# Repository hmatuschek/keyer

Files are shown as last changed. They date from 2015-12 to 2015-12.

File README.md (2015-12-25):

# Electronic touch CW keyer
This tiny circuit and its firmware implements a simple electronic CW keyer using capacitive touch-paddles. Hence it has absolutely no moving parts which eases the build of the mechanical part of the keyer a lot. 

The central logic of the keyer is implemented in software using a ATTiny 45 MCU. It implements a simple (mode A) electronic CW key. The capacitive touch interface is easy too. It basically measures the capacity of the metal paddles which changes as they get touched with the hand. In fact, the hardware measures the time needed to charge the paddles though a large resistor. This time increases significantly if the paddle is touched. 

The circuit provides a open-collector output to switch even simple transmitters which expect a straight key. Additionally an LED and a side-tone generator are present for practicing. The speed of the keyer can be set using a potentiometer in a range from 10WPM to 42WPM. Please note that the speed gets updated only while the key is idle.

## License
Both, the hard and software are licensed under the terms of the GNU Public License (GPL).

Copyright (C) 2015  Hannes Matuschek <hmatuschek at gmail dot com>

This program is free software; you can redistribute it and/or modify it under the terms of the GNU General Public License as published by the Free Software Foundation; either version 2 of the License, or (at your option) any later version.

This program is distributed in the hope that it will be useful, but WITHOUT ANY WARRANTY; without even the implied warranty of MERCHANTABILITY or FITNESS FOR A PARTICULAR PURPOSE.  See the GNU General Public License for more details.

You should have received a copy of the GNU General Public License along with this program; if not, write to the Free Software Foundation, Inc., 51 Franklin Street, Fifth Floor, Boston, MA 02110-1301 USA.

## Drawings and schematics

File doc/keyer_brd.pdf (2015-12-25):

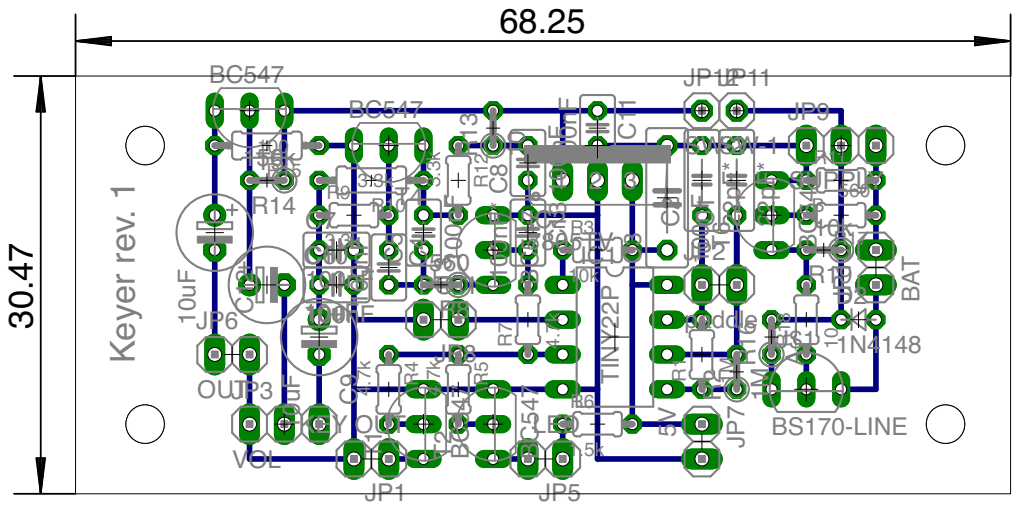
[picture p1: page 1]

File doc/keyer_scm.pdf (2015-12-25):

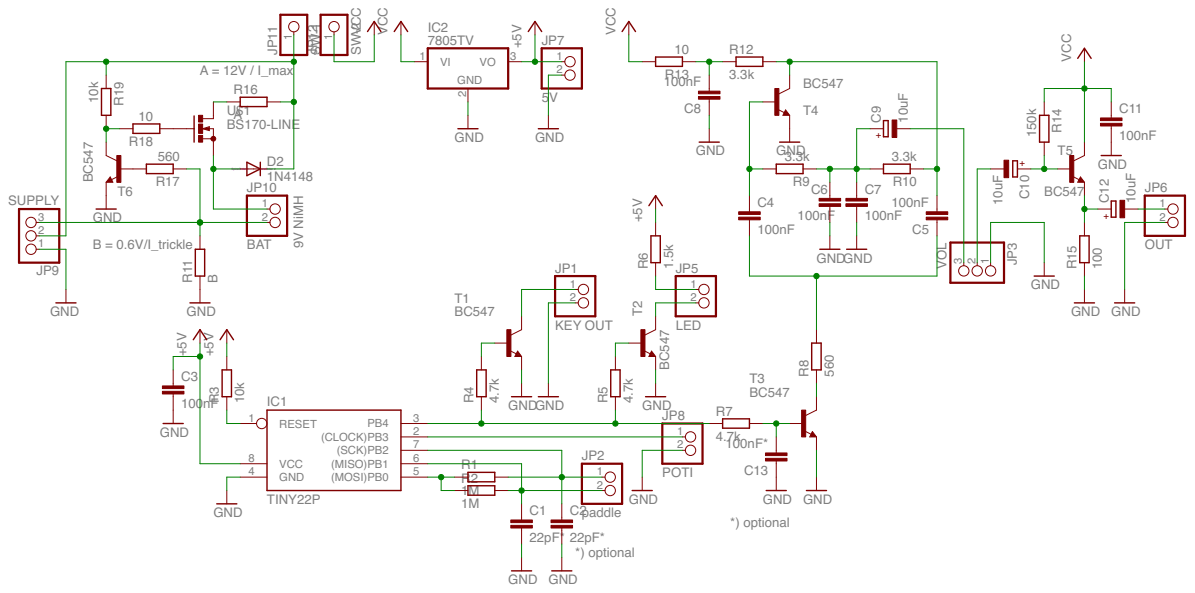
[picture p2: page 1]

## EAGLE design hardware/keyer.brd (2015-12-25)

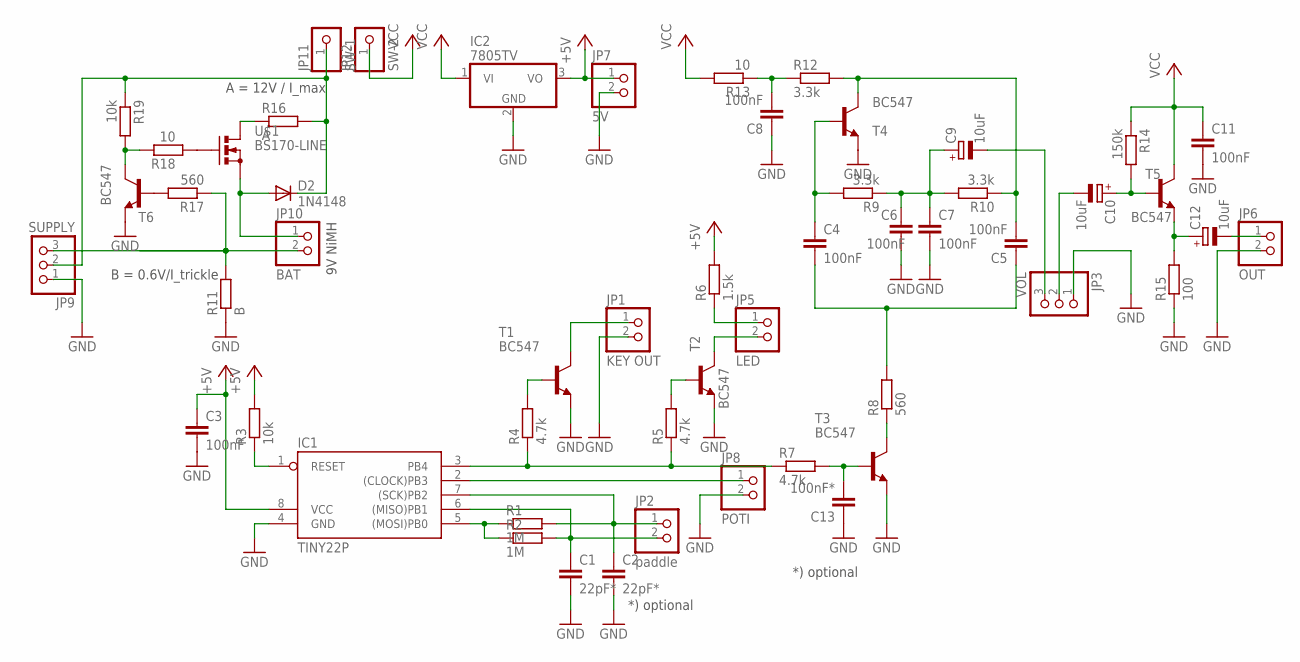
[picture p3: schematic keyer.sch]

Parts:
C1, C2: 22pF*; C050-025X075
C3: 100nF; C075-032X103
C4, C5, C6, C7, C8, C11: 100nF; C025-025X050
C9, C10, C12: 10uF; E2,5-6
C13: 100nF*; C025-025X050
D2: 1N4148; D-2.5
IC1: TINY22P; DIL08
IC2: 7805TV; TO220V
JP1: KEY OUT; 1X02
JP2: paddle; 1X02
JP3: VOL; 1X03
JP5: LED; 1X02
JP6: OUT; 1X02
JP7: 5V; 1X02
JP8: POTI; 1X02
JP9: SUPPLY; 1X03
JP10: BAT; 1X02
JP11: SW-1; 1X01
JP12: SW-2; 1X01
R1: 1M; 0204/5
R2: 1M; 0204V
R3: 10k; 0204/5
R4, R5, R7: 4.7k; 0204/5
R6: 1.5k; 0204/5
R8: 560; 0204V
R9, R12: 3.3k; 0204/5
R10: 3.3k; 0204/7
R11: B; 0204/5
R13: 10; 0204V
R14: 150k; 0204V
R15: 100; 0204/7
R16: A; 0204V
R17: 560; 0204/5
R18: 10; 0204/5
R19: 10k; 0204V
T1, T2, T3, T4, T5, T6: BC547; TO92-CBE
U$1: BS170-LINE; TO92-LINE

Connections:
+5V: C3.1, IC1.8 (VCC), IC2.3 (VO), JP7.1, R3.2, R6.2
GND: C1.2, C2.2, C3.2, C6.2, C7.2, C8.1, C11.2, C13.1, IC1.4 (GND), IC2.2 (GND), JP1.2, JP3.1, JP6.2, JP7.2, JP8.2, JP9.1, R11.1, R15.1, T1.E, T2.E, T3.E, T4.E, T6.E
unnamed: IC1.5 ((MOSI)PB0), R1.1, R2.1
unnamed: C2.1, IC1.7 ((SCK)PB2), JP2.1, R1.2
unnamed: C1.1, IC1.6 ((MISO)PB1), JP2.2, R2.2
unnamed: IC1.1 (RESET), R3.1
unnamed: IC1.2 ((CLOCK)PB3), JP8.1
unnamed: R4.2, T1.B
unnamed: JP1.1, T1.C
unnamed: IC1.3 (PB4), R4.1, R5.1, R7.1
unnamed: R8.1, T3.C
unnamed: R5.2, T2.B
unnamed: JP5.2, T2.C
unnamed: JP5.1, R6.1
unnamed: C4.1, R9.2, T4.B
unnamed: C13.2, R7.2, T3.B
unnamed: C5.2, R10.1, R12.2, T4.C
unnamed: JP9.3, JP10.2, R11.2, R17.1
unnamed: C6.1, C7.1, C9.+, R9.1, R10.2
unnamed: C4.2, C5.1, R8.2
unnamed: C8.2, R12.1, R13.1
unnamed: C9.-, JP3.3
unnamed: C10.-, JP3.2
unnamed: C10.+, R14.2, T5.B
unnamed: C12.+, R15.2, T5.E
unnamed: C12.-, JP6.1
unnamed: R17.2, T6.B
unnamed: D2.A, JP10.1, U$1.1 (S)
unnamed: R16.1, U$1.3 (D)
unnamed: R18.1, U$1.2 (G)
unnamed: R18.2, R19.2, T6.C
unnamed: D2.C, JP9.2, JP11.1, R16.2, R19.1
VCC: C11.1, IC2.1 (VI), JP12.1, R13.2, R14.1, T5.C

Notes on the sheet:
9V NiMH
A = 12V / I_max
B = 0.6V/I_trickle
*) optional

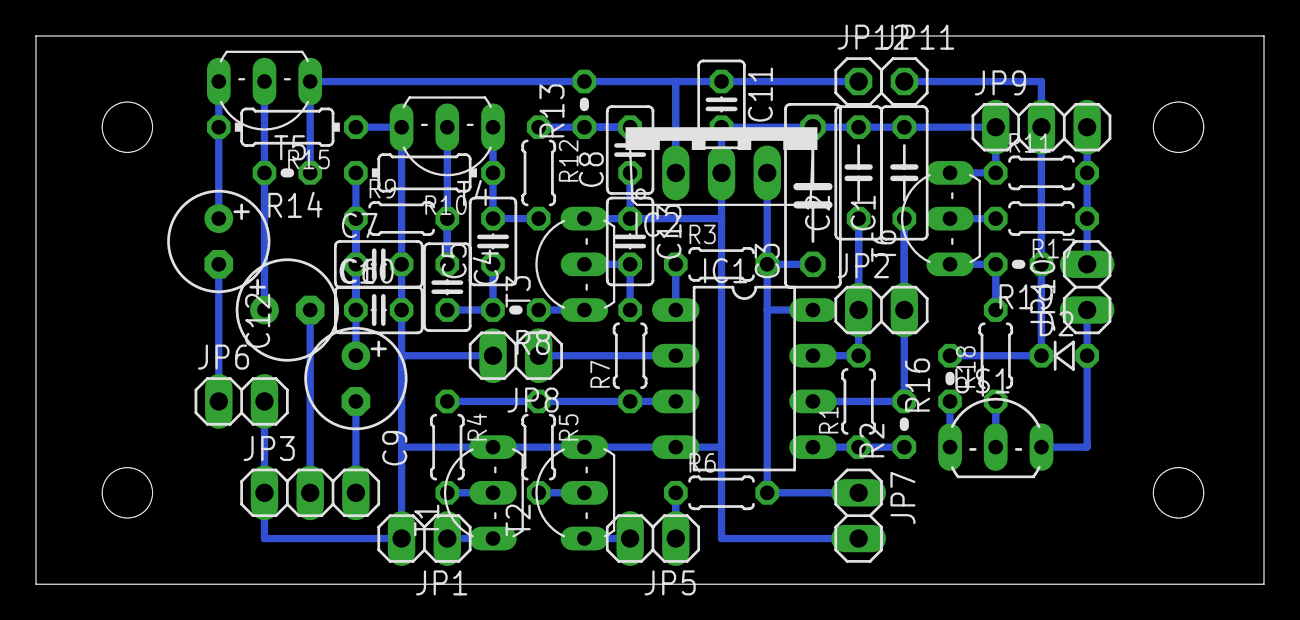
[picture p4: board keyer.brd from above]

Board: 2 copper layers, 68.2 x 30.5 mm, 53 parts (0 on the bottom side), 33 nets.

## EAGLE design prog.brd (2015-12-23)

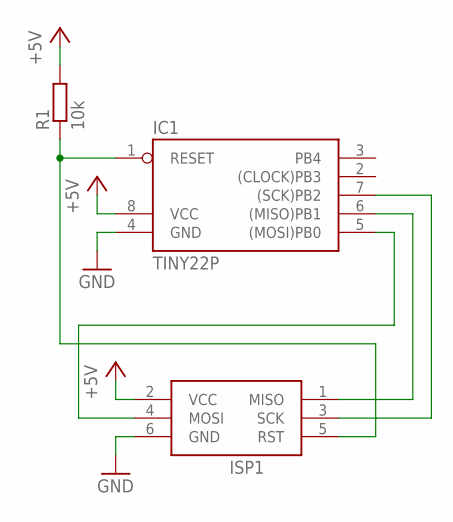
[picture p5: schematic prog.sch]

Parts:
IC1: TINY22P; DIL08
ISP1: AVRISP-6; AVRISP
R1: 10k; 0204/7

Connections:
+5V: IC1.8 (VCC), ISP1.2 (VCC), R1.2
GND: IC1.4 (GND), ISP1.6 (GND)
unnamed: IC1.1 (RESET), ISP1.5 (RST), R1.1
unnamed: IC1.5 ((MOSI)PB0), ISP1.4 (MOSI)
unnamed: IC1.6 ((MISO)PB1), ISP1.1 (MISO)
unnamed: IC1.7 ((SCK)PB2), ISP1.3 (SCK)

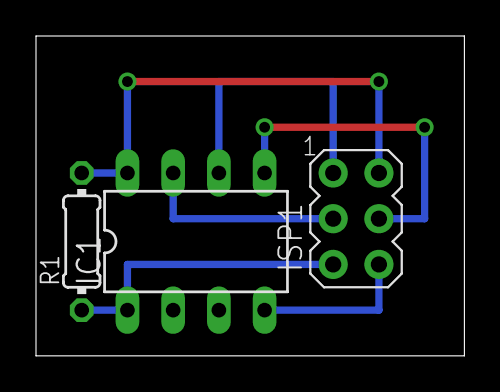
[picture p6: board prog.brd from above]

Board: 2 copper layers, 23.8 x 17.8 mm, 3 parts (0 on the bottom side), 6 nets.

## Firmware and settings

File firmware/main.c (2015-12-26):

/* Firmware for the CW touch key (paddle).
 *
 * (c) 2015, Hannes Matuschek <hmatuschek at gmail dot com>
 *
 * This firmware implements an electronic key using two simple metal paddles
 * (connected to PB1 & PB2) that are triggered by touching them. Touching a paddle causes the
 * capacity of the paddle to increase. This can be detected by measureing the time needed to charge
 * the paddle through a huge resistor (about 1MOhm). Touching the left paddle will generate a series
 * of dots (dit) while touching the right paddle will generate a series of dahses (dah). Touching
 * both paddles at the same time, a series of dot and dash alternations are generated. If the left
 * paddle was touched first, the series starts with a dash. If the right paddle was
 * touched first, the series starts with a dot. This is equivalent to the behavior of an
 * iambic CW key (mode A).
 *
 * The speed (between 10 and 43 WPM) can be chosen by a potentiometer connected to PB3 (ADC3). The
 * output is connected to PB4. This pin controls an open-collector output to controll the
 * transmitter, an LED and a 600Hz side-tone generator.
 */

#include <avr/io.h>
#include <avr/interrupt.h>
#include <util/delay.h>
#include <avr/cpufunc.h>
#include <avr/pgmspace.h>

/// Keep the delay short
#define MAX_DELAY (F_CPU/1000UL)
/// Helper macro to return the maximum of two values
#define max(a,b) (a<b ? b : a)


// LUT of 32 dit-lengths values (in ms),
// (approx) linear in WPM, from 10 to 42 WPM.
static const uint16_t dit_len_lut[] = {
  120, 109, 100,  92,  86,  80,  75,  70,
   67,  63,  60,  57,  54,  52,  50,  48,
   46,  44,  43,  41,  40,  39,  37,  36,
   35,  34,  33,  32,  31,  30,  29,  28};


/// Initializes the touch interface
void init_touch() {
  // set PB0 as output
  DDRB  |= (1 << DDB0);
  // set PB0 to 0
  PORTB &= ~(1 << DDB0);
  // set PB1 & PB2 as output (low Z, for now)
  DDRB  |= ((1 << DDB1) | (1 << DDB2));
  // set 0 (GND), keeps paddles discharged
  PORTB &= ~((1 << DDB1) | (1 << DDB2));
}

/// Read touch paddles, returns 0b00 if no paddle is touched,
/// 0b01 if only the left is touched, 0b10 if only the right is
/// touched and 0b11 if both are touched.
uint8_t read_touch(uint32_t thres) {
  // config sense pins as input (high impedance)
  DDRB  &= ~((1<<DDB1) | (1<<DDB2));
  // start charging, set PB0 -> 1
  PORTB |= (1<<DDB0);
  // delay
  for (uint32_t i=0; i<thres; i++) { _NOP(); }
  // check values (if the pin is still 0, the paddle is touched).
  uint8_t value = ((PINB>>1) & 0x03) ^ 0x03;
  // discharge paddles...
  PORTB &= ~(1<<DDB0);  // set PB0 -> 0
  // ... set sense pins as output (low impedance)
  DDRB  |= ((1<<DDB1) | (1<<DDB2));
  // ... set sense pin to 0 (GND)
  PORTB &= ~( (1<<DDB1) || (1<<DDB2) );
  // wait for a short time to discharge completely
  _delay_us(10);
  // done.
  return value;
}

/// Calibrate the touch interface
uint32_t calibrate_touch() {
  uint32_t thres = 1;
  // Increment threshold until touch detects no value
  while (read_touch(thres) && (thres<MAX_DELAY)) {
    thres++;
  }
  // Increase threshold for reliable detection
  // (this decreses the sensitivity for the sake
  // of reduced false-positives). The factor depends
  // on the hardware and may you need to experiment with
  // this value.
  return 2*thres;
}


/// Configures the timer interrupt to be triggered every 1ms.
void init_timer() {
  // Set Timer on Compare Match (CTC) mode
  TCCR0A = 0x02;
  // clock source CLK/16
  TCCR0B = 0x03;
  // -> 1ms
  OCR0A  = 125-1;
  // enable interrupt (OC 0A)
  TIMSK  = (1<<OCIE0A);
}


/// Configures the output.
void init_key() {
  // set PB4 as output
  DDRB  |= (1 << DDB4);
  PORTB &= ~(1 << DDB4);
}

/// Sets the output.
void key(uint8_t on) {
  if (on) { PORTB |= (1<<DDB4); }
  else { PORTB &= ~(1<<DDB4); }
}

/// Toggles the output.
void toggle_key() {
  PORTB ^= (1<<DDB4);
}


/// Initializes the ADC.
void init_adc() {
  // Set as input (high Z)
  DDRB  &= ~(1 << DDB3);
  // Disable digital input buffer of PB3
  DIDR0 |= (1 << ADC3D);
  // Config prescaler (no iterrupt, auto trigger, ADC still disabled)
  ADCSRA = (0 << ADEN) | (0 << ADSC) | (0 << ADATE) | (0 << ADIF) | (0 << ADIE) |
      (1<<ADPS2) | (1<<ADPS1) | (1<<ADPS0);
  // Vcc reference, ADC3 input
  ADMUX = (0<<REFS2) | (0<<REFS1) | (0<<REFS0) | (0<<ADLAR) |
      (0<<MUX3) | (0<<MUX2) | (1<<MUX1) | (1<<MUX0);
  // enable ADC
  ADCSRA |= (1<<ADEN);
}

/// Starts a new conversion.
void start_adc() {
  ADCSRA |= (1<<ADSC);
}

/// Returns true if the ADC is ready.
uint8_t adc_available() {
  return (0 == (ADCSRA & (1<<ADSC)));
}

/// Returns the ADC value as a 5-bit (0,...,31) value.
uint8_t adc_value() {
  return (ADCW>>5);
}

/// Returns the dit length in ms as defined by the ADC value.
uint16_t get_dit_len() {
  // Simply return the corresponding LUT value
  //return pgm_read_word_near(&dit_len_lut[adc_value() % 32]);
  return dit_len_lut[adc_value() % 32];
}


/** Possible states of the state machine. */
typedef enum {
  IDLE,         ///< Idle, wait for keys.
  SEND_DIT,     ///< Send a dit.
  SEND_DAH      ///< Send a dah.
} State;

/// The current state.
volatile State state = IDLE;
/// The last state.
volatile State last_state = IDLE;
/// The current dit length in ms.
/// Gets updated on startup.
volatile uint16_t dit_len = 60;
// Precomputed multiples of ditlen
volatile uint16_t dit_2len = 2*60;
volatile uint16_t dit_3len = 3*60;
volatile uint16_t dit_4len = 4*60;


int main(void)
{
  // Init timer interrupt
  init_timer();
  // Init touch interface
  init_touch();
  // Init output
  init_key();
  // Init ADC
  init_adc();

  // Calibrate the touch interface,
  // take the maximum threshold from 100 trials
  uint32_t thres = 0;
  for (uint8_t i=0; i<100; i++) {
    thres = max(thres, calibrate_touch());
  }

  // on calibration error
  // (delay threshold to large, sould not happen)
  while (MAX_DELAY == thres) {
    // -> blink trap
    toggle_key();
    _delay_ms(200);
  }

  // Measure speed setting...
  start_adc();
  // ... wait for the ADC to finish
  while (! adc_available()) { }
  // ... compute dit lenght
  dit_len = get_dit_len();
  // ... precompute some multiples of dit len
  dit_2len = 2*dit_len; dit_3len = 3*dit_len; dit_4len = 4*dit_len;

  // enable interrupts globally
  sei();

  // Go.
  state = IDLE;
  last_state = IDLE;

  // Poll paddles.
  while(1)
  {
    // If waiting for the next symbol...
    if (IDLE == state) {
      // ... dispatch by paddle state
      // (left -> dit, right -> dah, both -> alternate dit & dah)
      switch (read_touch(thres)) {
        // On left paddle
        case 0x01:
          last_state = IDLE;
          state = SEND_DIT;
          break;

        // On right paddle
        case 0x02:
          last_state = IDLE;
          state = SEND_DAH;
          break;

        // On both paddles alternate dit & dah
        case 0x03:
          if (SEND_DIT == last_state) {
            // If last state was a dit -> send dah
            last_state = SEND_DIT;
            state = SEND_DAH;
          } else {
            // If last state was a dah -> send dit
            last_state = state;
            state = SEND_DIT;
          }
          break;

        // Otherwise stay in idle
        default:
          break;
      }

      // If still in idle -> check speed dial and update dit length
      if ((IDLE == state) && adc_available()) {
        // If ADC is ready, update dit len
        dit_len = get_dit_len();
        // Precompute multiples of dit len
        dit_2len = 2*dit_len; dit_3len = 3*dit_len; dit_4len = 4*dit_len;
        // and restart measurement
        start_adc();
      }
    }
  }
}


ISR (TIMER0_COMPA_vect)
{
  static uint16_t count = 0;

  if (SEND_DIT == state) {
    // Send a dit (10, with additional pause)
    if (0 == count) {
      key(1); count++;
    } else if (dit_len == count) {
      key(0); count++;
    } else if (dit_2len == count) {
      last_state = SEND_DIT;
      state = IDLE;
      count = 0;
    } else {
      count++;
    }
  } else if (SEND_DAH == state) {
    // Send a dah (1110, with additional pause)
    if (0 == count) {
      key(1); count++;
    } else if (dit_3len == count) {
      key(0); count++;
    } else if (dit_4len == count) {
      last_state = SEND_DAH;
      state = IDLE;
      count = 0;
    } else {
      count++;
    }
  }
}
